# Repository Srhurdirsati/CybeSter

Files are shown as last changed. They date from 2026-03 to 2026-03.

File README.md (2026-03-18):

# CyberSter

Cyberster is a portable MP3 player using different electronic modules. It can play music from an SD card and send audio through AUX or Bluetooth. A screen is used to show the menu and song information. The device also uses a Type-C port for power and transferring music files.

## Complete Hardware & BOM Table

Go to bom.csv for BOM 

## Features 

> MP3 playback from SD card

> Scrollable music list

> Basic UI on TFT screen

> Play / Pause / Next / Previous controls

> Volume adjustment

> Sleep mode

> Automatic next-track playback

> Aux Output

The display needs to be just vertically mounted on the mounting poles .

## Usage 

> Install Arduino IDE.

> Install the ESP32 board package.

> Install the required libraries:

> Adafruit VS1053

> Adafruit GFX

> Adafruit ST7789

> SPI

> SD

> Open the firmware file.

> Select your ESP32 board.

> Upload the code.

Now you are done setting it up the firmware . 

Next you will need to plug the battery to the jst connector below the board and make sure its properly connected at appropriate poles. The buttons would be pressed by the 3d model of button which would be inserted from below the top plate at it's desired holes and it will automatically fit in that . No need to solder anything .

## Future Possible Updates

> Bt support

> Inbuilt Speaker

> Playlist

> Better Animations, etc.

## Images

















## JLCPCB

Capture

ESP32

DISPLAY

This was my most difficult and complex project till now and most timetaking so I just wan't to say that PCB won't feel easy at all if you are a beginner and also make sure u have enough knowledge to start .

TFT = 13 USD, ESP-32 = 7 USD, JLC = 67 

Total = 87 USD With Shipping

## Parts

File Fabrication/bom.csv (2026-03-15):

ID | Name | Designator | Footprint | Quantity | Manufacturer Part | Manufacturer | Supplier | Supplier Part | Price
1 | 10uF | C1,C2,C9,C10 | C0603 | 4 | CL10A106KP8NNNC | SAMSUNG(三星) | LCSC | C19702 | 0.007
2 | 1uF | C21,C25 | C0603 | 2 | CL10A105KB8NNNC | SAMSUNG(三星) | LCSC | C15849 | 0.007
3 | 22pF | C23,C24 | C0402 | 2 | 04025A220KAT2A | Kyocera AVX | LCSC | C597024 | 0.003
4 | VS1053B | U2 | LQFP-48_L7.0-W7.0-P0.50-LS9.0-BL | 1 | VS1053B-L | VLSI | LCSC | C9922 | 5.498
5 | AMS1117-3.3 | U3 | SOT-223-3_L6.5-W3.4-P2.30-LS7.0-BR | 1 | AMS1117-3.3 | AMS | LCSC | C6186 | 0.226
6 | 12MHz | U4 | CRYSTAL-SMD_4P-L3.2-W2.5-BL | 1 | 01.X.MH.120HHRI0012000000 | CREC(晶宝) | LCSC | C7462556 | 0.083
7 | TP4056 | U5 | ESOP-8_L4.9-W3.9-P1.27-LS6.0-BL-EP | 1 | TP4056-42-ESOP8 | TOPPOWER(南京拓微) | LCSC | C16581 | 0.183
8 | WAFER-PH2.0-2PWZ | U6 | CONN-TH_2P-P2.00_GP01-2001WR-2P | 1 | WAFER-PH2.0-2PWZ | XUNPU(讯普) | LCSC | C5359610 | 0.013
9 | TF-01A | CARD1 | TF-SMD_TF-01A | 1 | TF-01A | 韩国韩荣 | LCSC | C91145 | 0.188
10 | 5.8 WSGT-3P CC | SW1 | SW-TH_3P-L5.8_WSGT-3P-CC | 1 | 5.8 WSGT-3P CC | SHOU HAN(首韩) | LCSC | C22386787 | 0.183
11 | ESP32 | U1 | WIRELM-SMD_ESP32-S3-WROOM-1 | 1 | ESP32-S3-WROOM-1-N16R8 | ESPRESSIF(乐鑫) | LCSC | C2913202 | 5.747
12 | AUX | CN1 | AUDIO-SMD_HC-PJ-320A | 1 | HC-PJ-320A | HC(虹成电子) | LCSC | C7501806 | 0.035
13 | TYPE-C-31-M-12 | USBC1 | USB-C_SMD-TYPE-C-31-M-12_1 | 1 | TYPE-C-31-M-12 | 韩国韩荣 | LCSC | C165948 | 0.184
14 | SK12D07VG4 | SW8 | SW-TH_SK12D07VG4 | 1 | SK12D07VG4 | SHOU HAN(首韩) | LCSC | C393937 | 0.026
15 | 100nF | C7 | C0603 | 1 | CC0603KRX7R9BB104 | YAGEO(国巨) | LCSC | C14663 | 0.003
16 | 15-21SURC/S530-A3/3T | CHARGE | LED1206-R-RD_RED | 1 | 15-21SURC/S530-A3/3T | EVERLIGHT(亿光) | LCSC | C2984265 | 0.023
17 | 5.1kΩ | R1,R2 | R0603 | 2 | 0603WAF5101T5E | UNI-ROYAL(厚声) | LCSC | C23186 | 0.001
18 | 10kΩ | R6 | R0603 | 1 | SCR0603J10K | VO(翔胜) | LCSC | C3017715 | 0.001
19 | 1.2kΩ | R7 | R0603 | 1 | 0603WAD1201T5E | UNI-ROYAL(厚声) | LCSC | C423085 | 0.005
20 | PLAY | SW3 | KEY-SMD_4P-L6.0-W6.0-P4.50-LS9.0 | 1 | TS-1002S-07026C | XUNPU(讯普) | LCSC | C455114 | 0.06
21 | Next | SW4 | KEY-SMD_4P-L6.0-W6.0-P4.50-LS9.0 | 1 | TS-1002S-07026C | XUNPU(讯普) | LCSC | C455114 | 0.06
22 | PREV | SW5 | KEY-SMD_4P-L6.0-W6.0-P4.50-LS9.0 | 1 | TS-1002S-07026C | XUNPU(讯普) | LCSC | C455114 | 0.06
23 | UP | SW6 | KEY-SMD_4P-L6.0-W6.0-P4.50-LS9.0 | 1 | TS-1002S-07026C | XUNPU(讯普) | LCSC | C455114 | 0.06
24 | DOWN | SW7 | KEY-SMD_4P-L6.0-W6.0-P4.50-LS9.0 | 1 | TS-1002S-07026C | XUNPU(讯普) | LCSC | C455114 | 0.06
25 | MENU | SW9 | KEY-SMD_4P-L6.0-W6.0-P4.50-LS9.0 | 1 | TS-1002S-07026C | XUNPU(讯普) | LCSC | C455114 | 0.06
26 | 1-1123723-8 | CN2 | CONN-TH_1-1123723-8 | 1 | 1-1123723-8 | TE Connectivity(泰科电子) | LCSC | C498700 | 0.48

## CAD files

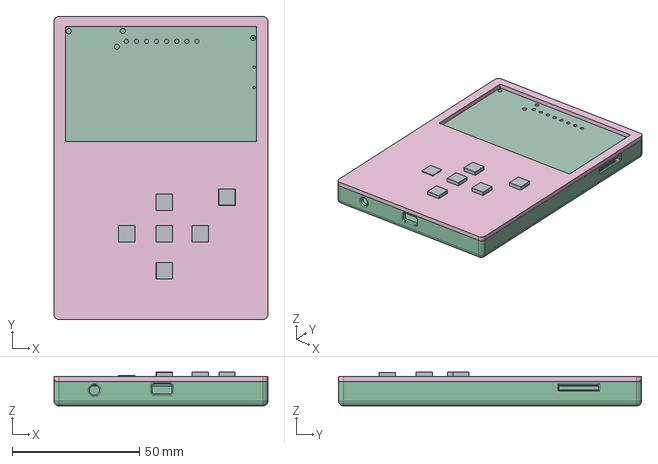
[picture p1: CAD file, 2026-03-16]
CAD/ASS-Assembly.step
84.0 x 119.0 x 13.3 mm
1_PCB

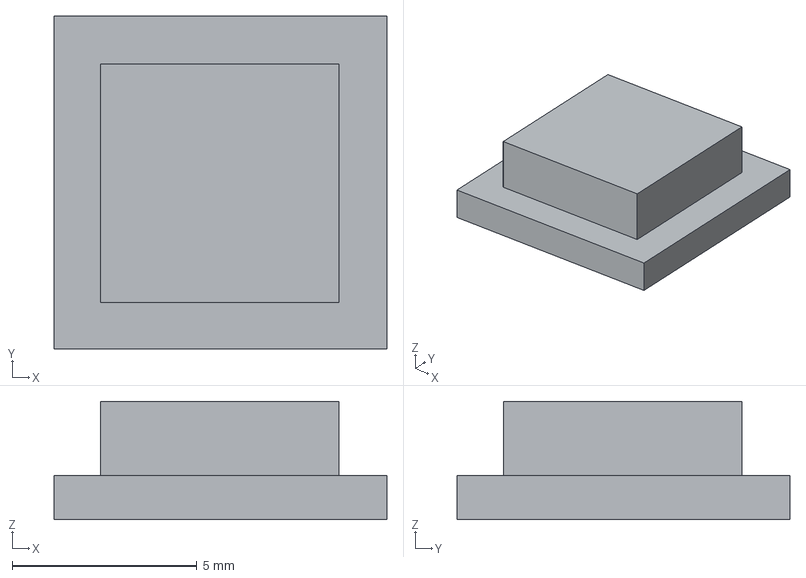
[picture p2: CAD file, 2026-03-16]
CAD/PRODUCTION/BUTTON-Part.step
9.00 x 9.00 x 3.20 mm

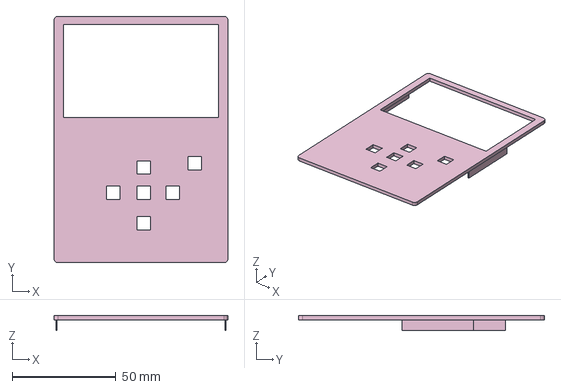
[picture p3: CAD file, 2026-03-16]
CAD/Top Plate-Part.step
84.0 x 119.0 x 7.00 mm

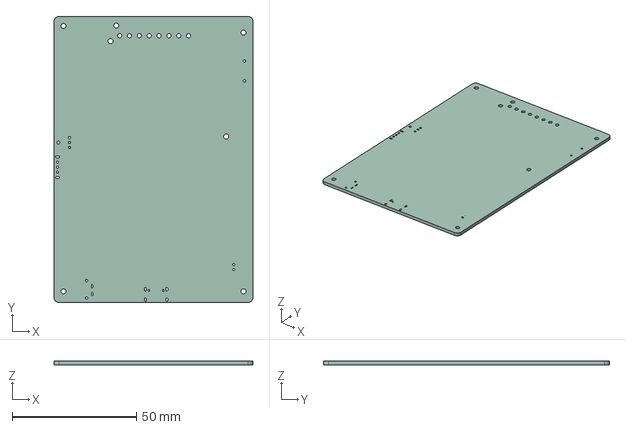
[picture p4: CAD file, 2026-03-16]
CAD/PCB.step
80.0 x 115.0 x 1.51 mm

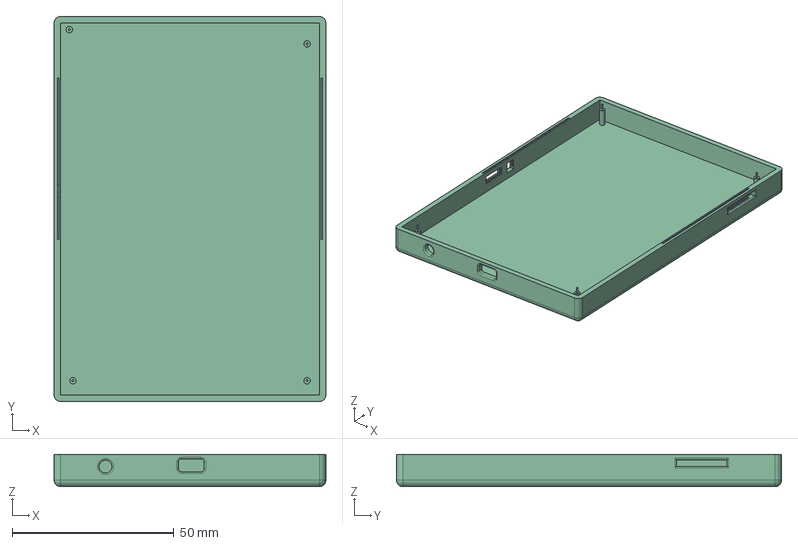
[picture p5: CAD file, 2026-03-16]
CAD/Bottom Case-Part.step
84.0 x 119.0 x 10.0 mm

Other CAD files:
CAD/BUTTON.FCStd

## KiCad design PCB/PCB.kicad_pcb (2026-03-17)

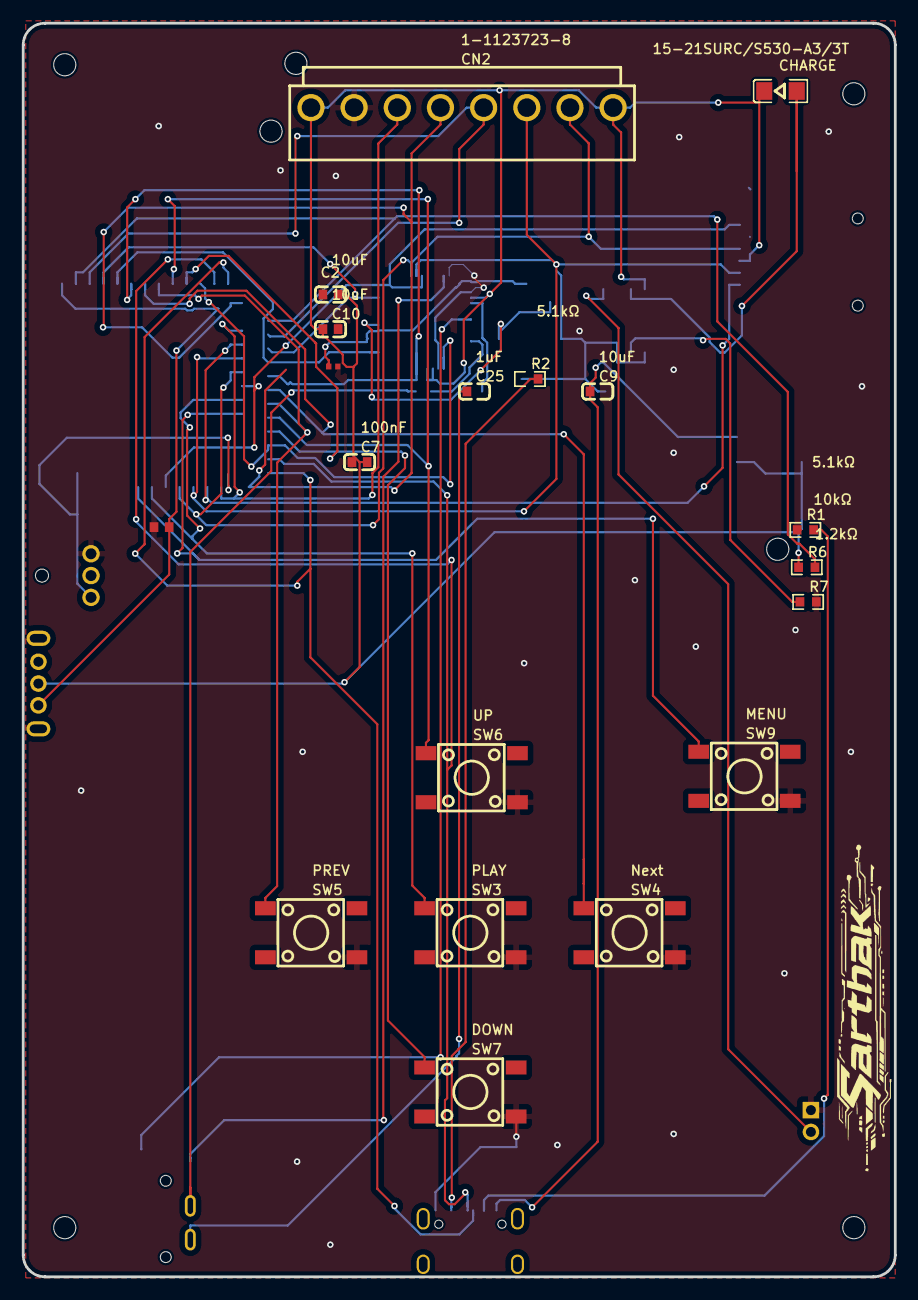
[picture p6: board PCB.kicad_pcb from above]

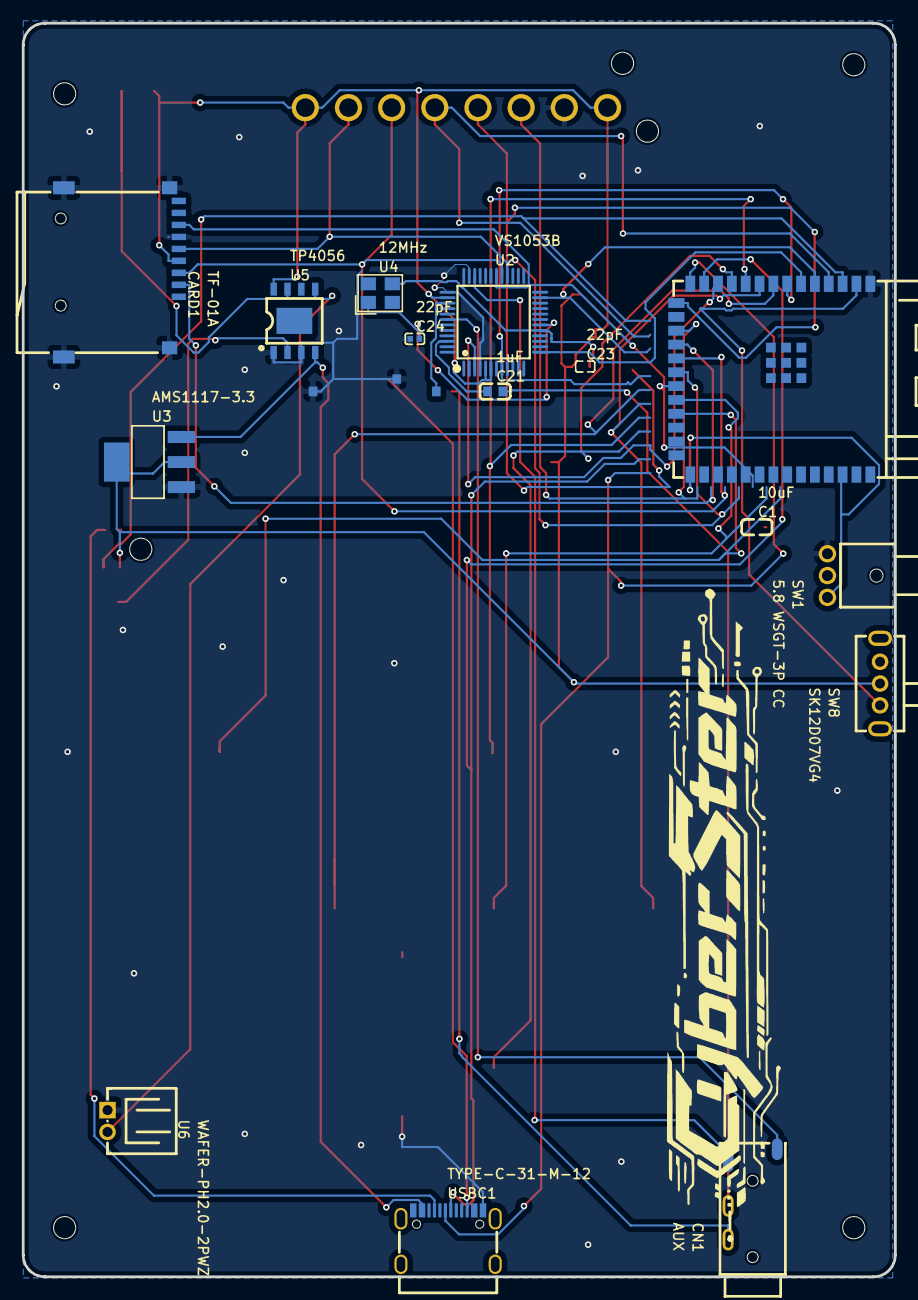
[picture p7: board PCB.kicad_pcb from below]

Board: 2 copper layers, 80.0 x 115.0 mm, 39 parts (15 on the bottom side), 38 nets.

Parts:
C1, C2, C9, C10: 10uF; C0603
C7: 100nF; C0603
C21, C25: 1uF; C0603
C23, C24: 22pF; C0402
CARD1: TF-01A; TF-SMD_TF-01A
CHARGE: 15-21SURC/S530-A3/3T; LED1206-R-RD_RED
CN1: AUX; AUDIO-SMD_HC-PJ-320A
CN2: 1-1123723-8; CONN-TH_1-1123723-8
Hole_gge20538: Hole_gge20538
Hole_gge20553: Hole_gge20553
Hole_gge20568: Hole_gge20568
Hole_gge20583: Hole_gge20583
Hole_gge20613: Hole_gge20613
Hole_gge20670: Hole_gge20670
Hole_gge20700: Hole_gge20700
R1, R2: 5.1kΩ; R0603
R6: 10kΩ; R0603
R7: 1.2kΩ; R0603
SW1: 5.8 WSGT-3P CC; SW-TH_3P-L5.8_WSGT-3P-CC
SW3: PLAY; KEY-SMD_4P-L6.0-W6.0-P4.50-LS9.0
SW4: Next; KEY-SMD_4P-L6.0-W6.0-P4.50-LS9.0
SW5: PREV; KEY-SMD_4P-L6.0-W6.0-P4.50-LS9.0
SW6: UP; KEY-SMD_4P-L6.0-W6.0-P4.50-LS9.0
SW7: DOWN; KEY-SMD_4P-L6.0-W6.0-P4.50-LS9.0
SW8: SK12D07VG4; SW-TH_SK12D07VG4
SW9: MENU; KEY-SMD_4P-L6.0-W6.0-P4.50-LS9.0
U1: ESP32; WIRELM-SMD_ESP32-S3-WROOM-1
U2: VS1053B; LQFP-48_L7.0-W7.0-P0.50-LS9.0-BL
U3: AMS1117-3.3; SOT-223-3_L6.5-W3.4-P2.30-LS7.0-BR
U4: 12MHz; CRYSTAL-SMD_4P-L3.2-W2.5-BL
U5: TP4056; ESOP-8_L4.9-W3.9-P1.27-LS6.0-BL-EP
U6: WAFER-PH2.0-2PWZ; CONN-TH_2P-P2.00_GP01-2001WR-2P
USBC1: TYPE-C-31-M-12; USB-C_SMD-TYPE-C-31-M-12_1

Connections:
3V: C2.2, C7.2, C10.1, CARD1.4, CHARGE.2, CN2.1, CN2.8, R6.1, SW8.2, U2.5, U2.6, U2.38, U3.2, U3.4, U5.8
5V: C9.1, U3.3, U5.4, USBC1.A4B9
DETECT: CN1.4, U2.34
GBUF: CN1.1, U2.42
GND: C1.2, C2.1, C7.1, C9.2, C10.2, C23.1, C24.1, CARD1.6, CARD1.10, CARD1.11, CARD1.12, CARD1.13, CN2.2, R1.1, R2.1, R7.2, SW1.3, SW3.4, SW4.4, SW5.4, SW6.4, SW7.4, SW9.4, U1.1, U2.4, U2.35, U2.37, U3.1, U5.1, U5.3, U6.1, USBC1.B1A12
LEFT: C21.2, CN1.3
MENU: SW9.1, U1.23
MISO: CARD1.7, U1.21, U2.30
MOSI: CARD1.3, CN2.6, U1.19, U2.29
NEXT: SW4.1, U1.8
PLAY: SW3.1, U1.22
PREV: SW5.1, U1.9
RIGHT: C25.1, CN1.2
SCLK: CARD1.5, CN2.7, U1.20, U2.28
SDCARDCS: CARD1.2, U1.18
SW3.3: C1.1, SW8.1, U1.2
TFTAO: CN2.5, U1.4
TFTT_RST: CN2.4, U1.15
TFT_CS: CN2.3, U1.17
U1_3: R6.2, U1.3
U1_27: SW1.1, U1.27
U2_39: C25.2, U2.39
U2_46: C21.1, U2.46
U5_2: R7.1, U5.2
U5_5: U5.5, U6.2
U5_7: CHARGE.1, U5.7
USBC1_A5: R1.2, USBC1.A5
USBC1_B5: R2.2, USBC1.B5
USBD+: U1.14, USBC1.A6
USBD-: U1.13, USBC1.A7
V+: SW6.1, U1.10
V-: SW7.1, U1.11
VS1053_DREQ: U1.7, U2.8
VS1053_RST: U1.12, U2.3
VS1053_XCS: U1.5, U2.23
VS1053_XDCS: U1.6, U2.13
XTALI: C24.2, U2.18, U4.1
XTALO: C23.2, U2.17, U4.3

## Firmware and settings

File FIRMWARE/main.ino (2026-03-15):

#include <SPI.h>
#include <SD.h>
#include <Adafruit_VS1053.h>
#include <Adafruit_GFX.h>
#include <Adafruit_ST7789.h>

// VS1053
#define VS1053_CS 5
#define VS1053_DCS 6
#define VS1053_DREQ 7
#define VS1053_RST 8

// SD
#define SD_CS 10

// TFT
#define TFT_CS 9
#define TFT_DC 4
#define TFT_RST 3

// Buttons
#define BTN_PLAY 14
#define BTN_NEXT 15
#define BTN_PREV 16
#define BTN_UP 17
#define BTN_DOWN 18
#define BTN_MENU 21

// Battery
#define BAT_ADC 1

#define MAX_SONGS 200
#define SCREEN_W 240
#define SCREEN_H 240

Adafruit_ST7789 tft = Adafruit_ST7789(TFT_CS, TFT_DC, TFT_RST);

Adafruit_VS1053_FilePlayer player =
Adafruit_VS1053_FilePlayer(
VS1053_RST,
VS1053_CS,
VS1053_DCS,
VS1053_DREQ,
SD_CS
);

String songList[MAX_SONGS];
int songCount = 0;

int selected = 0;
int currentSong = -1;

bool playing = false;

int volume = 20;

int scrollOffset = 0;

unsigned long lastUI = 0;

void scanFiles(File dir) {

while(true){

File entry = dir.openNextFile();

if(!entry) break;

String name = entry.name();

if(name.endsWith(".MP3") || name.endsWith(".mp3")){

songList[songCount++] = name;

}

entry.close();

}

}

float readBattery(){

int raw = analogRead(BAT_ADC);

float voltage = raw * (3.3 / 4095.0) * 2;

return voltage;

}

int batteryPercent(){

float v = readBattery();

if(v >= 4.2) return 100;
if(v >= 4.0) return 85;
if(v >= 3.8) return 60;
if(v >= 3.6) return 40;
if(v >= 3.4) return 20;
return 5;

}

void drawHeader(){

tft.fillRect(0,0,240,30,ST77XX_BLUE);

tft.setCursor(5,8);
tft.setTextColor(ST77XX_WHITE);
tft.setTextSize(2);
tft.print("MP3 Player");

int bat = batteryPercent();

tft.setCursor(180,8);
tft.print(bat);
tft.print("%");

}

void drawList(){

tft.fillRect(0,30,240,170,ST77XX_BLACK);

for(int i=0;i<6;i++){

int index = scrollOffset + i;

if(index >= songCount) break;

if(index == selected){

tft.fillRect(0,30 + i*28,240,28,ST77XX_GREEN);

tft.setTextColor(ST77XX_BLACK);

}else{

tft.setTextColor(ST77XX_WHITE);

}

tft.setCursor(10,40 + i*28);

tft.print(songList[index]);

}

}

void drawPlayer(){

tft.fillRect(0,30,240,170,ST77XX_BLACK);

tft.setCursor(10,40);
tft.print("Playing:");

tft.setCursor(10,70);
tft.print(songList[currentSong]);

}

void drawProgress(){

if(!player.playingMusic) return;

uint32_t pos = player.currentPosition();
uint32_t len = player.playingMusicSize;

if(len == 0) return;

int w = (pos * 200) / len;

tft.drawRect(20,200,200,10,ST77XX_WHITE);

tft.fillRect(20,200,w,10,ST77XX_GREEN);

}

void playSelected(){

currentSong = selected;

player.stopPlaying();

player.startPlayingFile(songList[currentSong].c_str());

playing = true;

drawPlayer();

}

void handleButtons(){

if(!digitalRead(BTN_UP)){

selected--;

if(selected < 0) selected = 0;

if(selected < scrollOffset) scrollOffset--;

drawList();

delay(150);

}

if(!digitalRead(BTN_DOWN)){

selected++;

if(selected >= songCount) selected = songCount -1;

if(selected > scrollOffset + 5) scrollOffset++;

drawList();

delay(150);

}

if(!digitalRead(BTN_PLAY)){

if(currentSong == selected){

if(playing){

player.pausePlaying(true);

playing=false;

}else{

player.pausePlaying(false);

playing=true;

}

}else{

playSelected();

}

delay(200);

}

if(!digitalRead(BTN_NEXT)){

selected++;

if(selected >= songCount) selected = 0;

playSelected();

delay(200);

}

if(!digitalRead(BTN_PREV)){

selected--;

if(selected < 0) selected = songCount-1;

playSelected();

delay(200);

}

}

void sleepMode(){

player.stopPlaying();

tft.fillScreen(ST77XX_BLACK);

tft.setCursor(60,120);
tft.print("Sleeping");

delay(2000);

esp_deep_sleep_start();

}

void setup(){

Serial.begin(115200);

pinMode(BTN_PLAY,INPUT_PULLUP);
pinMode(BTN_NEXT,INPUT_PULLUP);
pinMode(BTN_PREV,INPUT_PULLUP);
pinMode(BTN_UP,INPUT_PULLUP);
pinMode(BTN_DOWN,INPUT_PULLUP);
pinMode(BTN_MENU,INPUT_PULLUP);

tft.init(240,240);
tft.setRotation(2);

if(!SD.begin(SD_CS)){

tft.print("SD Error");

while(1);

}

if(!player.begin()){

tft.print("VS1053 Error");

while(1);

}

player.setVolume(volume,volume);

scanFiles(SD.open("/"));

drawHeader();
drawList();

}

void loop(){

handleButtons();

if(millis() - lastUI > 300){

drawProgress();

drawHeader();

lastUI = millis();

}

if(!player.playingMusic && playing){

selected++;

if(selected >= songCount) selected = 0;

playSelected();

}

if(!digitalRead(BTN_MENU)){

sleepMode();

}

}
